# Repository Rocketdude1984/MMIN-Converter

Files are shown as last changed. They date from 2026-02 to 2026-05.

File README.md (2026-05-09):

# MM-IN Converter

Simple converter for mm to inches and inches to mm. Meant as a project to advance skills in PCB design and firmware development.

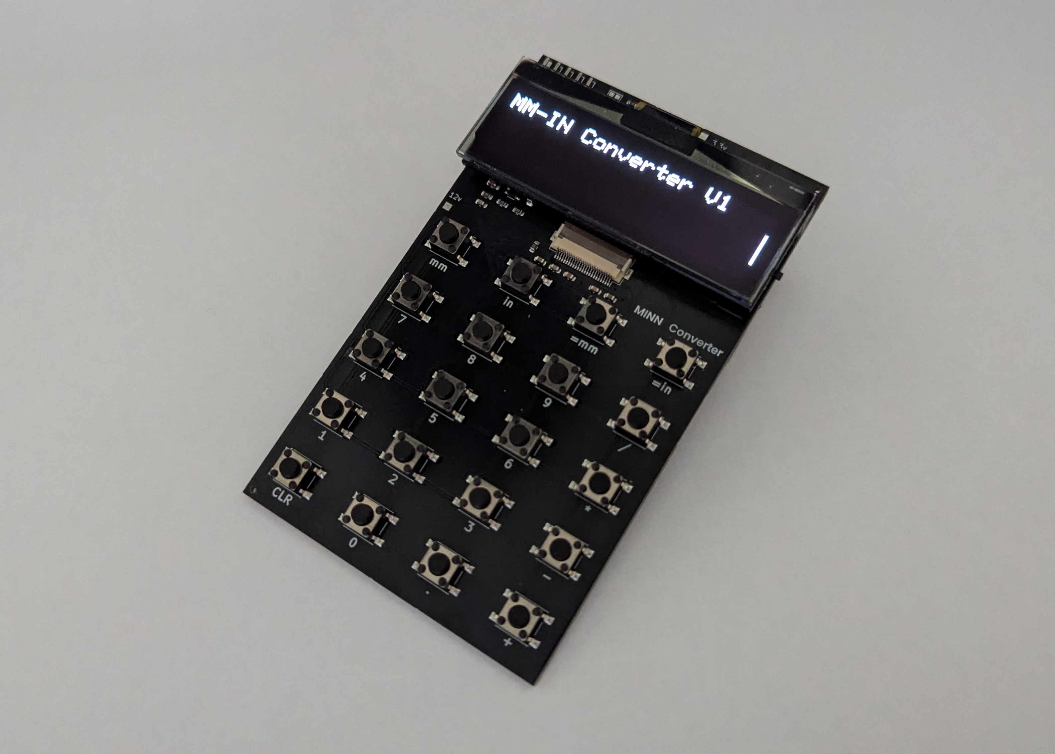
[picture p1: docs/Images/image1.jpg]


## Power
2xAA batteries

## Parts
- OLED screen - 2.23 Inch OLED LCD Display Module SSD1305 Drive IC 24 Pin 12832 LCD Screen Board 128x32 SPI Interface White https://www.amazon.com/dp/B0DYXSCPYH?ref_=ppx_hzsearch_conn_dt_b_fed_asin_title_5
- Battery Holder - Philmore BH321P https://www.ebay.com/itm/175575917461

## Prototype
- Button Matrix
- 128x32 OLED
- STM32F103C8 MCU
- TPS63020 buck-boost converter (3.3v)
- TPS61040 boost converter (12v)
- 2xAA battery holder

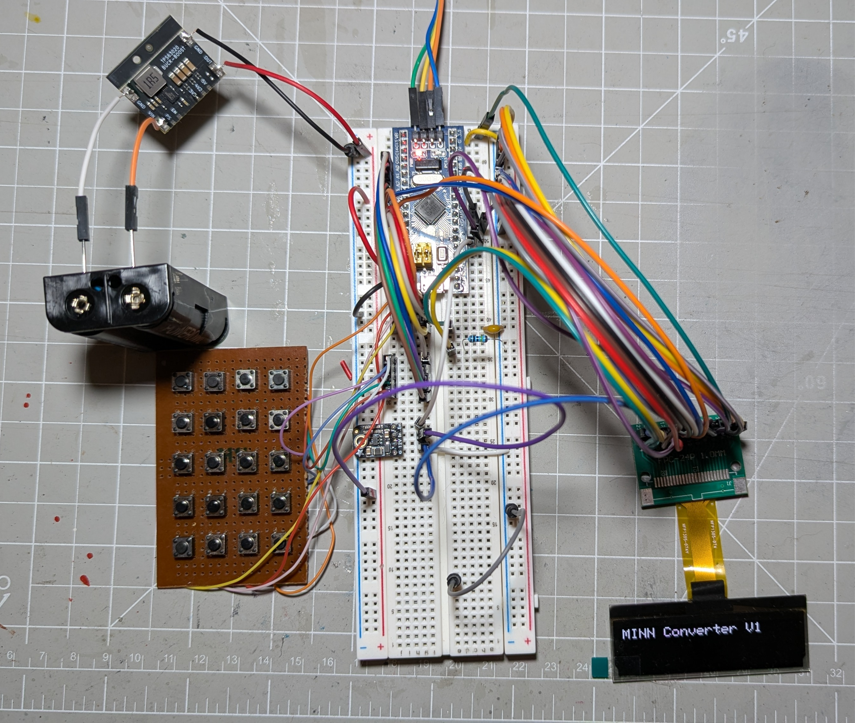
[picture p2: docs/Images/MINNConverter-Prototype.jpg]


Production took a while longer than expected, but the project is complete.

After correcting a few lines of code the converter works great.

## Construction

1. Make sure to solder the battery holder correctly.
2. Connect the OLED display to the connector before glueing any parts on.
3. I used a resin printer to make the battery shim and display holder and glued them to the board with gorilla glue.

## Changes
I made a few changes to the PCB based on what I learned from this first model.
Mainly I forgot to put the pin designations for the serial connections on the silkscreen. And having an "ON/OFF" indication would have been nice. I tried to implement that in a new version of the board, but it is still not great because screen and battery comepletely cover each side of the switch.

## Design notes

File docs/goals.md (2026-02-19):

# Goals

## Needs:
1. Create a calculator for converting mm to inches and inches to mm.
2. Have options for mathematical operations (+,-,*,/)
3. Have ability to enter values with a given unit (mm or in).
4. Raw PCB board design, with a focus on using only SMD components.
5. OLED display.
6. Small form-factor design (~2x3in).
7. USB-C or Battery power.
8. 4x4 button matrix
9. On/Off switch

## Wants:
- Black PCB
- Sleep function, auto wake on button press

## Timeline
8 Weeks
- 3 Weeks research and development
- 2 Weeks firmware and design
- 3 Weeks manufacturing

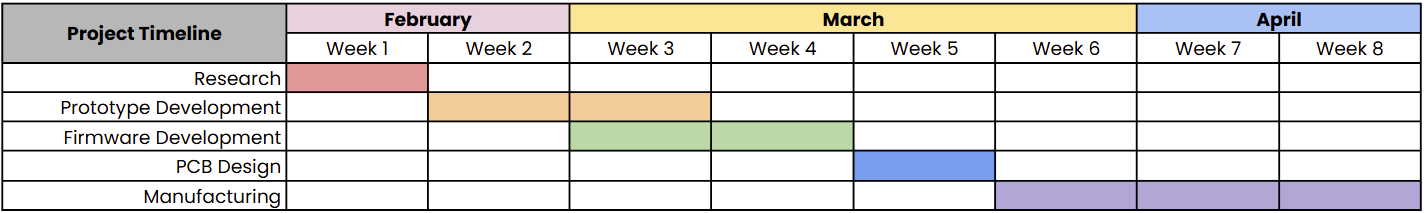
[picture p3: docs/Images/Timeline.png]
Project Timeline


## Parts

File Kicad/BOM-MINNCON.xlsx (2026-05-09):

Comment | Designator | Footprint | LCSC Part Number
4.7µF | C1,C2 | Capacitor_SMD:C_0805_2012Metric
100nF | C3, C4, C12, C15 | Capacitor_SMD:C_0603_1608Metric
10nF | C5, C11 | Capacitor_SMD:C_0603_1608Metric
1µF | C6, C13, C14, C_COMH1 | Capacitor_SMD:C_0603_1608Metric
4.7µF | C7 | Capacitor_SMD:C_0603_1608Metric
100nf | C8, C9, C10 | Capacitor_SMD:C_0603_1608Metric
22µF | C17, C_OUT_1, C_OUT_2, C_OUT_3 | Capacitor_SMD:C_0805_2012Metric
3.3pF | C_FF1 | Capacitor_SMD:C_0603_1608Metric
10µF | C_IN_1, C_IN_2 | Capacitor_SMD:C_0805_2012Metric
MBR0530 | D1 | Diode_SMD:D_SOD-123
LED | D2 | LED_SMD:LED_0603_1608Metric
SERIAL DEBUG | J1 | Connector_PinHeader_2.54mm:PinHeader_1x05_P2.54mm_Horizontal
OLED CONN | J2 | Connector_FFC-FPC:Hirose_FH12-24S-0.5SH_1x24-1MP_P0.50mm_Horizontal
3.3µH | L1 | Inductor_SMD:L_1008_2520Metric
1µH, 57mΩ | L2 | Inductor_SMD:L_Murata_DFE201610P
875kΩ | R1 | Resistor_SMD:R_0603_1608Metric
100kΩ | R2, R9 | Resistor_SMD:R_0603_1608Metric
1MΩ | R3, R8 | Resistor_SMD:R_0603_1608Metric
180kΩ | R4 | Resistor_SMD:R_0603_1608Metric
10kΩ | R5, R6 | Resistor_SMD:R_0603_1608Metric
330Ω | R7 | Resistor_SMD:R_0603_1608Metric
SW_Push | SW1, SW2, SW3, SW4, SW5, SW6, SW7, SW8, SW9, SW10, SW11, SW12, SW13, SW14, SW15, SW16, SW17, SW18, SW19, SW20 | Button_Switch_SMD:SW_Push_1P1T_NO_6x6mm_H9.5mm
MK-12C02-G020 | SW21 | MK12C02:MK-12C02-G020_GSW
TPS61040DBV | U1 | Package_TO_SOT_SMD:SOT-23-5
TPS63020QDSJTQ1 | U2 | TPS63020:DSJ14_2P85X1P58_TEX
STM32F103C8Tx | U3 | Package_QFP:LQFP-48_7x7mm_P0.5mm

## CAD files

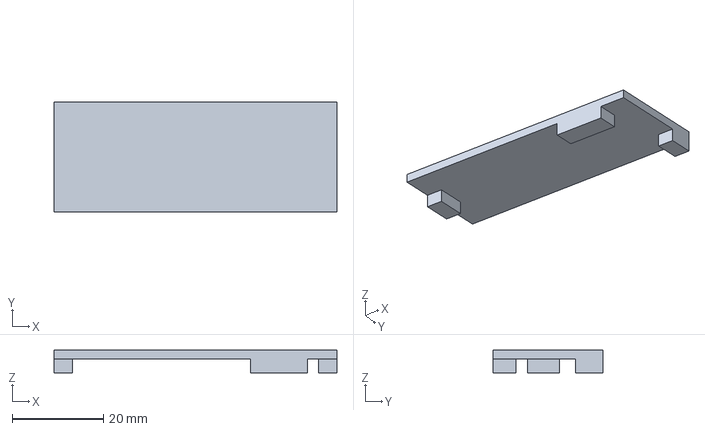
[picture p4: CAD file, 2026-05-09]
3D parts/ScreenHolder.FCStd
62.0 x 24.0 x 5.00 mm

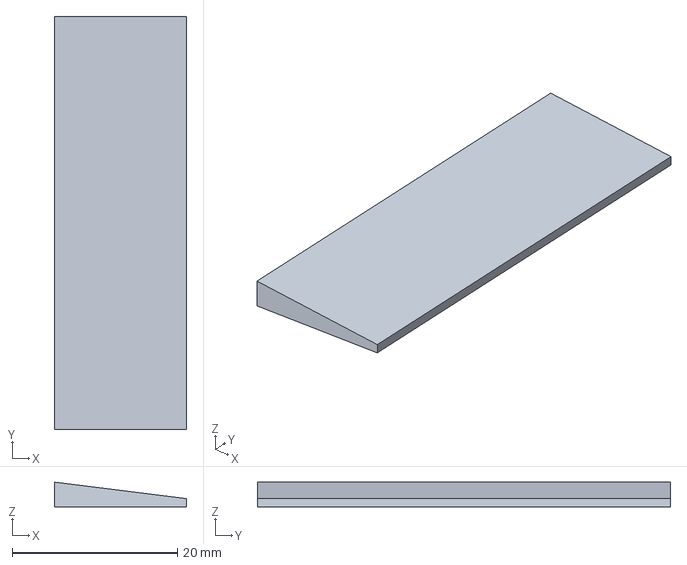
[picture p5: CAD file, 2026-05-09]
3D parts/BatteryShim.FCStd
16.0 x 50.0 x 3.00 mm

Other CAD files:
3D parts/BatteryShim.stl
3D parts/ScreenHolder.stl

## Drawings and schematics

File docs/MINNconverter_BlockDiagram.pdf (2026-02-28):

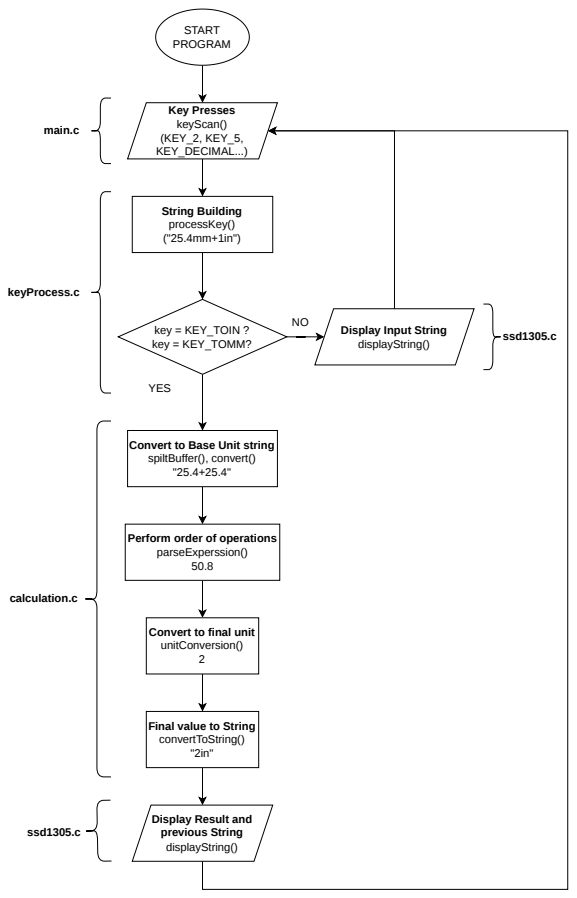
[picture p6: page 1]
Key Presses keyScan() (KEY_2, KEY_5, KEY_DECIMAL...); String Building processKey() ("25.4mm+1in"); key = KEY_TOIN ? key = KEY_TOMM?; YES; Display Input String; displayString(); START PROGRAM; calculation.c; ssd1305.c; keyProcess.c; main.c

Convert to Base Unit string
spiltBuffer(), convert()

Perform order of operations
parseExperssion()

Convert to final unit
unitConversion()

Final value to String
convertToString()

Display Result and
previous String
displayString()

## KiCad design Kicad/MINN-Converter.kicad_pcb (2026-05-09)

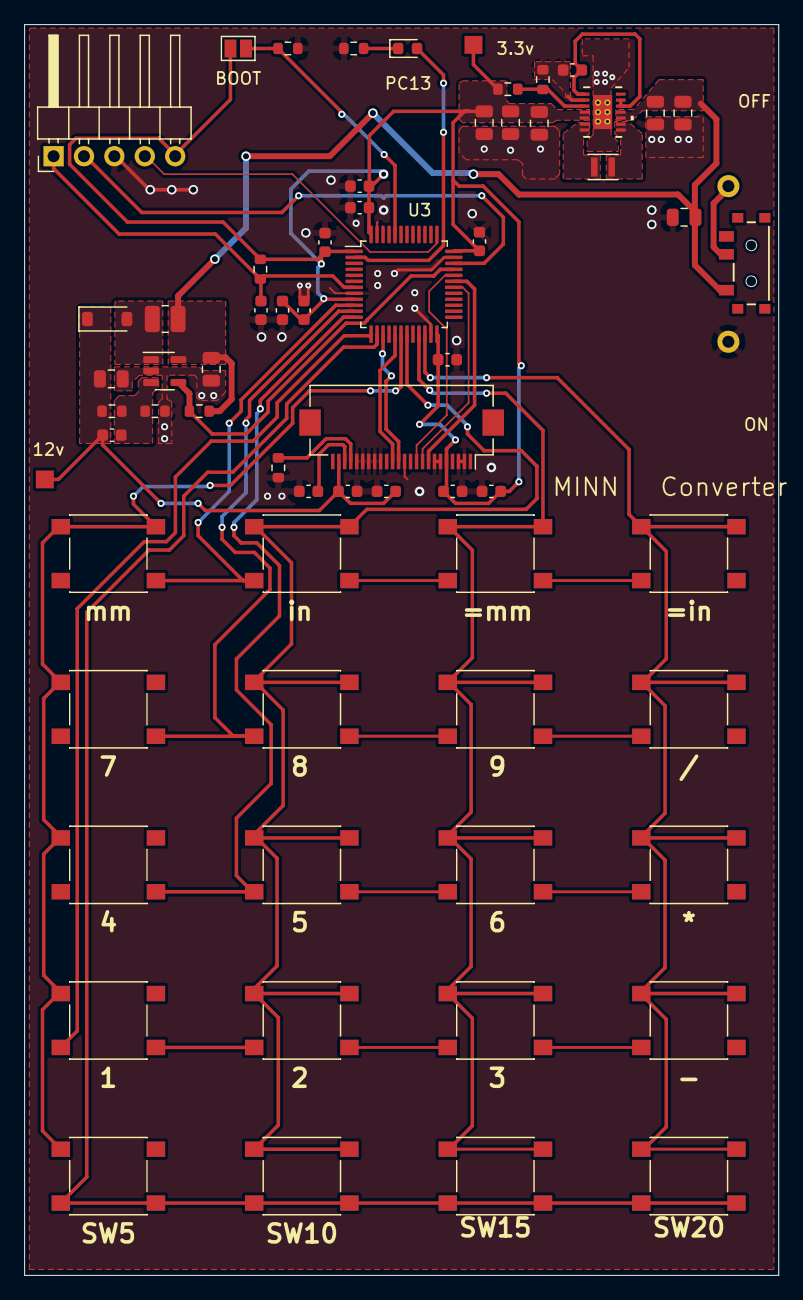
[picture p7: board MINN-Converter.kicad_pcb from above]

Board: 2 copper layers, 63.0 x 104.5 mm, 65 parts (0 on the bottom side), 33 nets.

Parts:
3.3v: +3.3V; TestPoint_Pad_1.5x1.5mm
12v: +12V; TestPoint_Pad_1.5x1.5mm
BOOT: SolderJumper_2_Open; SolderJumper-2_P1.3mm_Open_Pad1.0x1.5mm
C1: 4µF; C_0805_2012Metric
C2: 4.7µF; C_0805_2012Metric
C3, C4, C12, C15: 100nF; C_0603_1608Metric
C5, C11: 10nF; C_0603_1608Metric
C6, C13, C14: 1µF; C_0603_1608Metric
C7: 4.7µF; C_0603_1608Metric
C8, C9, C10: 100nf; C_0603_1608Metric
C17: 22µF; C_0805_2012Metric
C_COMH1: 1µF; C_0603_1608Metric
C_FF1: 3.3pF; C_0603_1608Metric
C_IN_1, C_IN_2: 10µF; C_0805_2012Metric
C_OUT_1, C_OUT_2, C_OUT_3: 22µF; C_0805_2012Metric
D1: MBR0530; D_SOD-123
D2: LED; LED_0603_1608Metric
J1: SERIAL DEBUG; PinHeader_1x05_P2.54mm_Horizontal
J2: OLED CONN; Hirose_FH12-24S-0.5SH_1x24-1MP_P0.50mm_Horizontal
L1: 3.3µH; L_1008_2520Metric
L2: 1µH, 57mΩ; L_Murata_DFE201610P
R1: 875kΩ; R_0603_1608Metric
R2, R9: 100kΩ; R_0603_1608Metric
R3, R8: 1MΩ; R_0603_1608Metric
R4: 180kΩ; R_0603_1608Metric
R5, R6: 10kΩ; R_0603_1608Metric
R7: 330; R_0603_1608Metric
SW1, SW2, SW3, SW4, SW5, SW6, SW7, SW8, SW9, SW10, SW11, SW12, SW13, SW14, SW15, SW16, SW17, SW18, SW19, SW20: SW_Push; SW_Push_1P1T_NO_6x6mm_H9.5mm
SW21: MK-12C02-G020; MK-12C02-G020_GSW
U1: TPS61040DBV; SOT-23-5
U2: TPS63020QDSJTQ1; DSJ14_2P85X1P58_TEX
U3: STM32F103C8Tx; LQFP-48_7x7mm_P0.5mm

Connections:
+3.3V: 3.3v.1, BOOT.2 (B), C4.1, C5.2, C6.1, C7.1, C8.1, C9.1, C10.1, C12.1, C13.1, C_OUT_1.1, C_OUT_2.1, C_OUT_3.1, J1.5, J2.5, R3.1, R5.1, U2.4 (VOUT), U2.5 (VOUT), U3.1 (VBAT), U3.9 (VDDA), U3.24 (VDD), U3.36 (VDD), U3.48 (VDD)
+12V: 12v.1, C2.1, C14.2, C15.2, C_FF1.1, D1.1 (K), J2.23, R1.1
BOOT0: BOOT.1 (A), R6.1, U3.44 (BOOT0)
COL_1: SW1.2, SW6.2, SW11.2, SW16.2, U3.10 (PA0)
COL_2: SW2.2, SW7.2, SW12.2, SW17.2, U3.11 (PA1)
COL_3: SW3.2, SW8.2, SW13.2, SW18.2, U3.12 (PA2)
COL_4: SW4.2, SW9.2, SW14.2, SW19.2, U3.13 (PA3)
COL_5: SW5.2, SW10.2, SW15.2, SW20.2, U3.14 (PA4)
CS: J2.8, U3.31 (PA10)
D/C: J2.10, U3.32 (PA11)
GND: C1.2, C2.2, C3.2, C4.2, C5.1, C6.2, C7.2, C8.2, C9.2, C10.2, C11.2, C12.2, C13.2, C14.1, C15.1, C17.2, C_COMH1.2, C_IN_1.2, C_IN_2.2, C_OUT_1.2, C_OUT_2.2, C_OUT_3.2, J1.3, J2.2, J2.3, J2.6, J2.7, J2.12, J2.16, J2.17, J2.18, J2.19, J2.20, R2.2, R4.2, R6.2, R7.1, R8.2, U1.2 (GND), U2.2 (GND), U2.15 (EPAD), U2.V, U3.8 (VSSA), U3.23 (VSS), U3.35 (VSS), U3.47 (VSS)
LED: D2.2 (A), U3.2 (PC13)
MOSI: J2.14, U3.17 (PA7)
NRST: C11.1, J1.1, R5.2, U3.7 (NRST)
unnamed: D1.2 (A), L1.2, U1.1 (SW)
unnamed: D2.1 (K), R7.2
unnamed: J2.21, R8.1
unnamed: C_COMH1.1, J2.22
unnamed: L2.1, U2.8 (L1), U2.9 (L1)
unnamed: L2.2, U2.6 (L2), U2.7 (L2)
unnamed: C_FF1.2, R1.2, R2.1, U1.3 (FB)
unnamed: C3.1, U2.1 (VINA), U2.12 (EN), U2.13 (PS/SYNC)
unnamed: R3.2, R4.1, U2.3 (FB)
RES: J2.9, U3.30 (PA9)
ROW_1: SW1.1, SW2.1, SW3.1, SW4.1, SW5.1, U3.18 (PB0)
ROW_2: SW6.1, SW7.1, SW8.1, SW9.1, SW10.1, U3.19 (PB1)
ROW_3: SW11.1, SW12.1, SW13.1, SW14.1, SW15.1, U3.21 (PB10)
ROW_4: SW16.1, SW17.1, SW18.1, SW19.1, SW20.1, U3.22 (PB11)
SCK: J2.13, U3.15 (PA5)
SWCLK: J1.4, U3.37 (PA14)
SWDIO: J1.2, U3.34 (PA13)
SW_OUT: C1.1, C17.1, C_IN_1.1, C_IN_2.1, L1.1, R9.1, SW21.1, U1.5 (VIN), U2.10 (VIN), U2.11 (VIN)
VCC_EN: R9.2, U1.4 (EN), U3.33 (PA12)

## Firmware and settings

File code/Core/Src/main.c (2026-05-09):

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
/* Includes ------------------------------------------------------------------*/
#include "main.h"
#include "spi.h"
#include "gpio.h"

/* USER CODE BEGIN Includes */
#include <stdint.h>
#include "processKey.h"
#include "calculator.h"
#include "constants.h"
#include "types.h"
#include "ssd1305.h"
/* USER CODE END Includes */

/* USER CODE BEGIN PTD */
# define ROWS 4
# define COLS 5

GPIO_TypeDef* rowPorts[ROWS] = {GPIOB, GPIOB, GPIOB, GPIOB};
uint16_t rowPins[ROWS] = {GPIO_PIN_0, GPIO_PIN_1, GPIO_PIN_10, GPIO_PIN_11};

GPIO_TypeDef* colPorts[COLS] = {GPIOA, GPIOA, GPIOA, GPIOA, GPIOA};
uint16_t colPins[COLS] = {GPIO_PIN_0, GPIO_PIN_1, GPIO_PIN_2, GPIO_PIN_3, GPIO_PIN_4};

uint32_t lastBlinkTime = 0;
uint8_t cursorVisible = 0;
/* USER CODE END PTD */


void SystemClock_Config(void);
/* USER CODE BEGIN PFP */
int keypadScan(void);
/* USER CODE END PFP */

/**
  * @brief  The application entry point.
  * @retval int
  */
int main(void)
{

  /* MCU Configuration--------------------------------------------------------*/

  /* Reset of all peripherals, Initializes the Flash interface and the Systick. */
  HAL_Init();

  /* Configure the system clock */
  SystemClock_Config();

  /* Initialize all configured peripherals */
  MX_GPIO_Init();
  MX_SPI1_Init();
  OLED_Init();
  OLED_Clear();
  drawString5x7("MM-IN Converter V1");
  /* USER CODE BEGIN 2 */
  calculator_t calc = {0};
  int key;

  /* USER CODE END 2 */

  /* Infinite loop */
  /* USER CODE BEGIN WHILE */
  while (1)
  {

	  // Inside your while(1) loop:
	  uint32_t currentTime = HAL_GetTick();

	  if (currentTime - lastBlinkTime >= BLINK_INTERVAL) {
	      lastBlinkTime = currentTime;
	      cursorVisible = !cursorVisible; // Toggle

	      // Update the display at the end of the input buffer
	      if (cursorVisible) {
	          drawCursor();
	          //HAL_GPIO_WritePin(LED_GPIO_Port, LED_Pin, GPIO_PIN_SET);
	      } else {
	          eraseCursor();
	          //HAL_GPIO_WritePin(LED_GPIO_Port, LED_Pin, GPIO_PIN_RESET);
	      }
	  }

    key = keypadScan();

	  if (key != -1){
		  HAL_Delay(20); //Debounce delay

		  if (key == keypadScan()){
			  
			  processKey(key, &calc);
			  drawString8x16(calc.input_buffer);

			  calc.input_length = strlen(calc.input_buffer);
			  /*
			  char lengthStr[4];
			  sprintf(lengthStr, "%u", calc.input_length);
			  drawString5x7(lengthStr);
			  */

	      //Wait until released
	      while (keypadScan() != -1);
		    }
	  }
    /* USER CODE END WHILE */

    /* USER CODE BEGIN 3 */
  }
  /* USER CODE END 3 */
}

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
/* USER CODE BEGIN 4 */
int keypadScan(void){
	for (int c = 0; c < COLS; c++){

		//Set all columns HIGH
		for (int i = 0; i < COLS; i++){
			HAL_GPIO_WritePin(colPorts[i], colPins[i], GPIO_PIN_SET);
		}

		//Pull current column LOW
		HAL_GPIO_WritePin(colPorts[c], colPins[c], GPIO_PIN_RESET);
		HAL_Delay(1);

		//Check rows
		for (int r = 0; r < ROWS; r++){
			if (HAL_GPIO_ReadPin(rowPorts[r], rowPins[r]) == GPIO_PIN_RESET){
				return (r * COLS) + c;
			}
		}
	}
	return -1;
}
/* USER CODE END 4 */
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


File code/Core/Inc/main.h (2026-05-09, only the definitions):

#define LED_Pin GPIO_PIN_13
#define LED_GPIO_Port GPIOC
#define RES_Pin GPIO_PIN_9 //9
#define RES_GPIO_Port GPIOA
#define CS_Pin GPIO_PIN_10 //10
#define CS_GPIO_Port GPIOA
#define D_C_Pin GPIO_PIN_11  //11
#define D_C_GPIO_Port GPIOA
#define VCC_EN_Pin GPIO_PIN_12 //12
#define VCC_EN_GPIO_Port GPIOA

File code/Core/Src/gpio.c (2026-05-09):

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

/* Includes ------------------------------------------------------------------*/
#include "gpio.h"

/*----------------------------------------------------------------------------*/
/* Configure GPIO                                                             */
/*----------------------------------------------------------------------------*/
/** Configure pins as
        * Analog
        * Input
        * Output
        * EVENT_OUT
        * EXTI
*/
void MX_GPIO_Init(void)
{

  GPIO_InitTypeDef GPIO_InitStruct = {0};

  /* GPIO Ports Clock Enable */
  __HAL_RCC_GPIOC_CLK_ENABLE();
  __HAL_RCC_GPIOA_CLK_ENABLE();
  __HAL_RCC_GPIOB_CLK_ENABLE();

  /*Configure GPIO pin Output Level */
  HAL_GPIO_WritePin(LED_GPIO_Port, LED_Pin, GPIO_PIN_RESET);

  /*Configure GPIO pin Output Level */
  HAL_GPIO_WritePin(GPIOA, GPIO_PIN_0|GPIO_PIN_1|GPIO_PIN_2|GPIO_PIN_3
                          |GPIO_PIN_4|CS_Pin|D_C_Pin, GPIO_PIN_SET);

  /*Configure GPIO pin Output Level */
  HAL_GPIO_WritePin(GPIOA, RES_Pin|VCC_EN_Pin, GPIO_PIN_RESET);

  /*Configure GPIO pin : LED_Pin */
  GPIO_InitStruct.Pin = LED_Pin;
  GPIO_InitStruct.Mode = GPIO_MODE_OUTPUT_PP;
  GPIO_InitStruct.Pull = GPIO_NOPULL;
  GPIO_InitStruct.Speed = GPIO_SPEED_FREQ_LOW;
  HAL_GPIO_Init(LED_GPIO_Port, &GPIO_InitStruct);

  /*Configure GPIO pins : PA0 PA1 PA2 PA3
                           PA4 RES_Pin CS_Pin D_C_Pin
                           VCC_EN_Pin */
  GPIO_InitStruct.Pin = GPIO_PIN_0|GPIO_PIN_1|GPIO_PIN_2|GPIO_PIN_3
                          |GPIO_PIN_4|RES_Pin|CS_Pin|D_C_Pin
                          |VCC_EN_Pin;
  GPIO_InitStruct.Mode = GPIO_MODE_OUTPUT_PP;
  GPIO_InitStruct.Pull = GPIO_NOPULL;
  GPIO_InitStruct.Speed = GPIO_SPEED_FREQ_LOW;
  HAL_GPIO_Init(GPIOA, &GPIO_InitStruct);

  /*Configure GPIO pins : PB0 PB1 PB10 PB11 */
  GPIO_InitStruct.Pin = GPIO_PIN_0|GPIO_PIN_1|GPIO_PIN_10|GPIO_PIN_11;
  GPIO_InitStruct.Mode = GPIO_MODE_INPUT;
  GPIO_InitStruct.Pull = GPIO_PULLUP;
  HAL_GPIO_Init(GPIOB, &GPIO_InitStruct);

}



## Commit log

2026-02-26 Add button press handling in buttonPress.c
2026-02-26 Clean up buttonPress.c by removing unused code
    Removed unused variables and commented out UART transmission.
2026-02-28 Core Folder for stm32IDE
2026-02-28 Block Diagram for current Logic FLow
2026-03-15 Updating Code
    Added display control, fonts, and fixed bugs
    [gpio.c, main.c, main.h]
2026-03-20 Adding prototype description
2026-03-21 Prototype Image
2026-03-21 Update image format for project prototype
2026-05-09 Uploading Finally core files
    Fixed OLED initialization, and changed to use internal clock.
    [gpio.c, main.c, main.h]
2026-05-09 3D printed parts folder
    [BatteryShim.FCStd, BatteryShim.stl, ScreenHolder.FCStd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]
2026-05-09 Uploads for the kicad project files
    Kicad project files, gerber files for manufacturing, BOM, and position file.
    [BOM-MINNCON.xlsx, MINN-Converter.kicad_pcb, MINN-Converter.kicad_sch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]
2026-05-09 Revise README with project details and updates
    Updated project title and added construction details and changes made to the PCB based on the first model's learnings.
2026-05-09 Update README with power and parts information
    Added power requirements and parts list to README.

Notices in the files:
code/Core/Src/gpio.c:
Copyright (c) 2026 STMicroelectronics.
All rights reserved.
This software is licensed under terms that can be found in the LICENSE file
